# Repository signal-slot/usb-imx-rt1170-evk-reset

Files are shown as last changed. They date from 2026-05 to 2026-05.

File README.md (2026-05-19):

# USB JTAG Reset Dongle for MIMXRT1170-EVKB

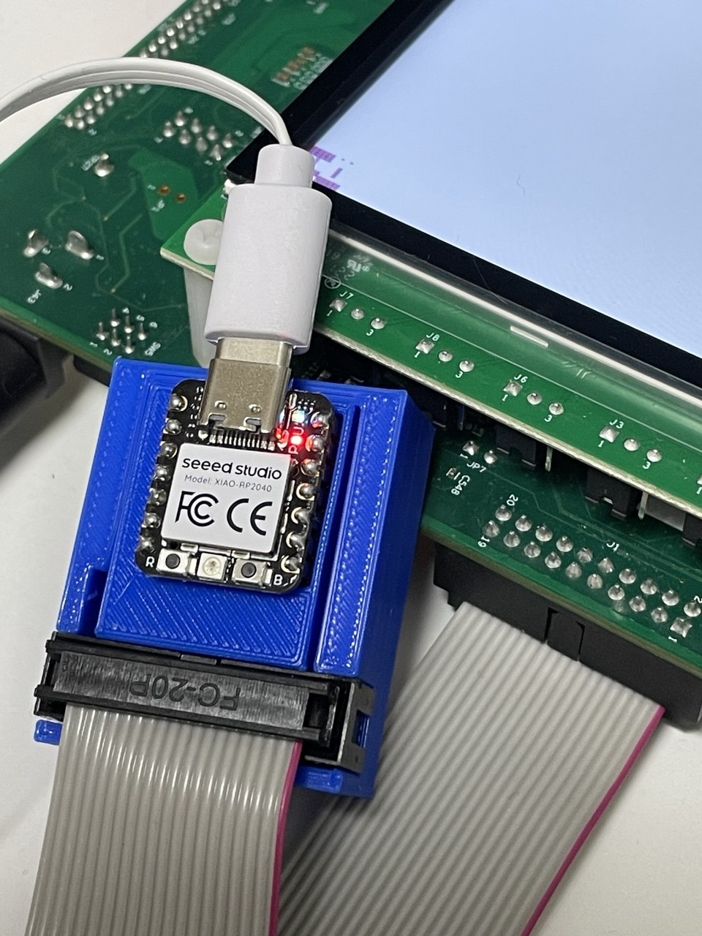
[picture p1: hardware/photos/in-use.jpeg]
MIMXRT1170-EVKB の J1 に接続して USB 経由でリセット


## 目次

1. [目的](#1-目的)
2. [採用した方式](#2-採用した方式)
3. [ハードウェア構成](#3-ハードウェア構成)(うち [フォトリレーとは](#フォトリレーとは))
4. [回路図](#4-回路図)
5. [抵抗の意味](#5-抵抗の意味)
6. [ユニバーサル基板レイアウト](#6-ユニバーサル基板レイアウト)(実機写真は [§6 実機写真](#実機写真) 参照)
7. [Rust ファームウェア方針](#7-rust-ファームウェア方針)
8. [動作確認項目](#8-動作確認項目)

ソースとアセット:

- ファームウェア: [`software/firmware/`](software/firmware/) (RP2040 Rust)
- ホスト CLI: [`software/cli/`](software/cli/) (`rt1170-cli`)
- 3D プリントケース: [`hardware/case/`](hardware/case/)
- 写真: [`hardware/photos/`](hardware/photos/)
- 仕様書(USDM): [`spec/usdm/`](spec/usdm/)

---

## 1. 目的

**最終目標**: AI コーディングエージェント([Claude Code](https://www.anthropic.com/claude-code) 等)が [MIMXRT1170-EVKB](https://www.nxp.com/design/design-center/development-boards-and-designs/i-mx-evaluation-and-development-boards/i-mx-rt1170-evaluation-kit:MIMXRT1170-EVKB) を使った組み込み開発を行う際、デバッガや SDK が **「SW4 を押してください」「ボードをリセットしてください」**と要求する場面を、AI 自身が `rt1170-cli reset` を呼ぶだけで自動化すること。人間がリセットボタンを押すまでループが止まる、という制約から AI を解放する。

そのために、MIMXRT1170-EVKB を Linux PC から USB 経由でリセットできる小型治具を作る。

当初は [SwitchBot](https://www.switch-bot.com/) のように物理的にタクトスイッチを押す案も検討したが、対象が基板上の SMD タクトスイッチであり、グラバーや物理押下機構が現実的でないため、最終的には **JTAG/SWD 20pin コネクタ上の reset 信号を電気的に短絡する方式**を採用する。

MIMXRT1170-EVKB の Hardware User Guide([NXP MIMXRT1170-EVKB ドキュメントページ](https://www.nxp.com/design/design-center/development-boards-and-designs/i-mx-evaluation-and-development-boards/i-mx-rt1170-evaluation-kit:MIMXRT1170-EVKB))では、J1 の JTAG/SWD コネクタに `POR_PIN_RST_B` が `JTAG_nSRST` として出ている。したがって、JTAG 20pin の `nSRST` と `GND` を一瞬短絡すれば、リセットボタン (**SW4**) を押したのと同等の操作ができる。

基本動作:

```text
Linux PC
  |
  | USB
  v
XIAO RP2040
  |
  | GPIO
  v
TLP241A PhotoMOS
  |
  | output contact
  v
JTAG nSRST / POR_PIN_RST_B  ── GND
```

Linux 側からは、例えば以下のように操作する。

```bash
echo "RESET 100" > /dev/ttyACM0
```

これにより、XIAO RP2040 が TLP241A を 100 ms だけ ON し、JTAG `nSRST` を GND に短絡する。

---

## 2. 採用した方式

### 最終方式

**USB CDC + XIAO RP2040 + TLP241A + 20pin JTAG IDC ケーブル**

### 採用理由

- MIMXRT1170-EVKB 側の SMD タクトスイッチを直接触らずに済む
- EVKB 側を改造しなくてよい
- JTAG/SWD 20pin コネクタから `nSRST` と `GND` を取り出せる
- TLP241A により XIAO 側と EVKB 側を絶縁できる
- Linux から `/dev/ttyACM0` 経由で簡単に制御できる
- XIAO RP2040 が手元にあり、Rust ファームウェアを書きやすい
- 13×8 の小型ユニバーサル基板に実装可能

---

## 3. ハードウェア構成

### フォトリレーとは

**フォトリレー**(PhotoMOS, [ソリッドステートリレー (SSR)](https://en.wikipedia.org/wiki/Solid-state_relay) の一種)は、光結合で入力と出力を電気的に絶縁したスイッチ。内部構造はおおよそ次のとおり:

- **入力側**: LED(発光ダイオード)
- **出力側**: MOSFET(機種により SCR や Triac のものもある)
- **絶縁**: LED と MOSFET の間は **光のみ**で結合。電気的には完全に分離されている

LED に電流を流して点灯させると、その光を受けた MOSFET がオンになり、出力側の接点が導通する。LED を消せばオフ。機械式リレーと違ってバウンスがなく、寿命が長く、スイッチング速度も速い。

このプロジェクトで採用している [**TLP241A**](https://akizukidenshi.com/goodsaffix/TLP241A_datasheet_ja_20230524.pdf)(東芝)は、出力 MOSFET が **双方向**(AC/DC どちらも切れる)、耐圧 60 V、`I_FT(max) = 5 mA` でトリガする 1 回路品。DIP-4 パッケージ。

### 主要部品

| 部品 | 用途 |
|---|---|
| [XIAO RP2040](https://wiki.seeedstudio.com/XIAO-RP2040/) | USB CDC デバイス兼 GPIO 制御 |
| [TLP241A](https://akizukidenshi.com/goodsaffix/TLP241A_datasheet_ja_20230524.pdf) | JTAG `nSRST` と `GND` を短絡する PhotoMOS / [フォトリレー](#フォトリレーとは) |
| 20pin IDC フラットケーブル | MIMXRT1170-EVKB の J1 JTAG/SWD コネクタへ接続 |
| 20pin 2×10 ヘッダ / IDC 受け | ユニバーサル基板側で IDC ケーブルを受ける |
| 13×8 ユニバーサル基板 | 実装基板 |
| 1kΩ 抵抗 | TLP241A 入力 LED の電流制限 (詳細は [§5](#5-抵抗の意味)) |
| 100kΩ 抵抗 | XIAO GPIO のプルダウン (詳細は [§5](#5-抵抗の意味)) |
| ピンソケット | XIAO RP2040 を着脱可能にする |

### 使用する信号

#### JTAG 20pin 側

一般的な ARM 20pin JTAG/SWD 配置では以下を使う。

```text
pin15 = nSRST / JTAG_nSRST / POR_PIN_RST_B
pin16 = GND
```

したがって TLP241A の出力側で以下を短絡する。

```text
JTAG pin15  <->  JTAG pin16
```

#### XIAO RP2040 側

XIAO は USB-C が下向きになるように配置する。  
制御ピンは、配置しやすい **D7 / GPIO1** を採用する。

```text
XIAO D7 / GPIO1 -> TLP241A input LED+
XIAO GND        -> TLP241A input LED-
```

---

## 4. 回路図

### 全体回路

TLP241A を中央に置き、**左半分が XIAO 側(LED 入力, 3.3V GND 系)**、**右半分が EVKB 側(MOSFET 出力, EVKB GND 系)**。チップ内部で光結合だけが両者をまたぎ、電気的には絶縁されている。

```text
   XIAO RP2040 側                  TLP241A                    EVKB J1 (JTAG 20pin)
   ─────────────                  ─────────                   ─────────────────────

                                ┌──────────┐
   D7/GPIO1 ●─┬─[ R1  1kΩ ]─────┤ 1      4 ├────────── ● pin 16 (GND, EVKB 側)
              │                 │  │     ║ │
              │                 │  ▼ LED ║ MOSFET   ← LED 点灯時に MOSFET 閉
              │                 │  │     ║ │
              └─[ R2 100kΩ ]──┐ │  │     ║ │
                              │ │  │     ║ │
   XIAO GND ●─────────────────●─┤ 2      3 ├────────── ● pin 15 (nSRST)
                                └──────────┘
                                  ◀────│────▶
                                  入力  │  出力
                                  (LED) │  (MOSFET)
                                        │
                                   絶縁境界(光結合のみ)
```

- pin 1, 2(チップ左) は XIAO 側 GND を基準とした 3.3V 系
- pin 3, 4(チップ右) は EVKB 側 GND を基準とした JTAG 信号
- 両 GND は同電位ではなく、TLP241A 内部で**完全に絶縁**されている

### JTAG 側

```text
MIMXRT1170-EVKB J1 / JTAG 20pin

pin15  nSRST / POR_PIN_RST_B  ---- TLP241A pin3
pin16  GND                    ---- TLP241A pin4
```

### XIAO 側

```text
XIAO D7 / GPIO1  ---- R1 1kΩ ----- TLP241A pin1
XIAO GND         ----------------- TLP241A pin2

XIAO D7 / GPIO1  ---- R2 100kΩ ---- XIAO GND
```

---

## 5. 抵抗の意味

### R1

TLP241A の入力 LED に流れる電流を制限するための抵抗。

- 推奨: **470Ω**
- 採用: **1kΩ**

### R2: 100kΩ

XIAO の GPIO が起動直後やリセット中に浮いて、TLP241A が誤 ON するのを防ぐためのプルダウン抵抗。

```text
XIAO D7/GPIO1 ---- 100kΩ ---- XIAO GND
```

---

## 6. ユニバーサル基板レイアウト

### 前提

- 基板: 13×8 ユニバーサル基板
- ポートレート配置
- 幅 8 穴 × 高さ 13 穴
- 20pin IDC は上側
- XIAO RP2040 は行7〜13
- XIAO は USB-C が下向き
- 20pin IDC は 8穴幅に対して左右 1 ピンずつはみ出す
- 抵抗は TLP241A の左側に置く

### 配置図

13×8 ユニバーサル基板 / 部品面・上から見る(USB-C を下、IDC を上にして縦置き):

部品面(XIAO 未装着、配線とパーツが全部見える):

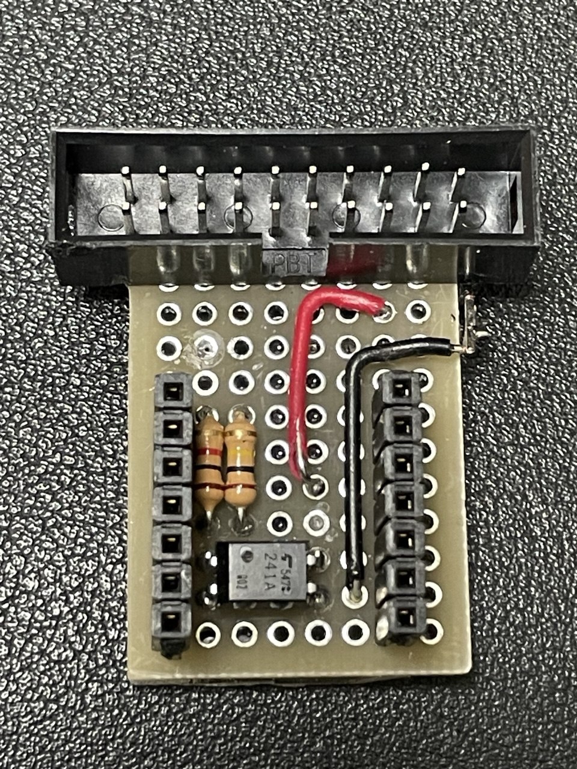
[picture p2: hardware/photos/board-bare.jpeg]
部品面・XIAO 未装着


| | | 1 | 2 | 3 | 4 | 5 | 6 | 7 | 8 | |  |
|:-:|:-:|:-:|:-:|:-:|:-:|:-:|:-:|:-:|:-:|:-:|:-:|
| | | | | | | | | ┌ | ─ | ─ | ┐ |
| r1 | ① | ③ | ⑤ | ⑦ | ⑨ | ⑪ | ⑬ | **⑮** | ⑰ | ⑲ | │ |
| r2 | ② | ④ | ⑥ | ⑧ | ⑩ | ⑫ | ⑭ | **⑯** | ⑱ | ⑳ | │ |
| r3 | | ・ | ・ | ・ | ・ | ・ | ・ | │ | ・ | | │ |
| r4 | | ・ | ・ | ・ | ・ | ┌ | ─ | ┘ | ・ | | │ |
| r5 | | ・ | ・ | ・ | ・ | │ | ┌ | ─ | ─ | ─ | ┘ |
| r6 | | ・ | ・ | ・ | ・ | │ | │ | ・ | ・ | | |
| r7 | | 7️⃣ | ┬ | ┐ | ・ | │ | │ | 6️⃣ | ・ | | |
| r8 | | 8️⃣ | Ｒ | Ｒ | ・ | │ | │ | 5️⃣ | ・ | | |
| r9 | | 9️⃣ | １ | ２ | ・ | │ | │ | 4️⃣ | ・ | | |
| 10 | | 🔟 | │ | │ | ・ | │ | │ | 3️⃣ | ・ | | |
| 11 | | 🔌 | P1 | │ | □ | P3 | │ | 2️⃣ | ・ | | |
| 12 | | ➖ | -2 | ┘ | □ | P4 | ┘ | 1️⃣ | ・ | | |
| 13 | | ➕ | ・ | ・ | ・ | ・ | ・ | 0️⃣ | ・ | | |
| | | | | Ｕ | Ｓ | Ｂ | | | | | |

凡例:

- `①`〜`⑳` … IDC ピン番号(囲み数字)。`⑮` (pin 15 = nSRST) と `⑯` (pin 16 = GND) のみ太字
- `・` … 空のホール
- `0️⃣`〜`9️⃣` `🔟` … XIAO の D0〜D10 ピン穴(囲み数字キーキャップ絵文字)
- `🔌` … 3V3、 `➖` … GND、 `➕` … 5V
- `Ｒ` `Ｒ` … R1 (1kΩ) / R2 (100kΩ) 本体、 `１` `２` … 抵抗ラベル
- `□` … TLP241A のチップ本体、 `P1`〜`P4` … 各ピン
- `┌` `┐` `┘` `─` `│` `┬` … 配線(IDC 渡り線、D7 分岐、R 末端ジャンパ)

XIAO ピン配置(USB-C を下向きにした縦置き、部品面・上から見る):

- **左ソケット**(行6→12): **D7/GPIO1**, D8, D9, D10, 3V3, **GND**, 5V
- **右ソケット**(行6→12): D6, D5, D4, D3, D2, D1, D0

レイアウト要点:

- R1 / R2 は左ソケット直右に縦置き 2 本、どちらも D7/GPIO1 から分岐
- TLP241A は基板中央、**左半分が LED 入力**(XIAO 側 GND を基準)、**右半分が MOSFET 出力**(EVKB 側 GND を基準)
- IDC の渡り線 2 本は中央 trench を縦に走り、TLP241A 右側の P3, P4 へ降下
- XIAO 側 GND と JTAG GND(EVKB 側)は TLP241A 内部で絶縁(直結なし)

### 穴位置(主要ホール)

```text
IDC pin15 (nSRST)       = 行1, 列7        ※ IDC は左右各 1 ピンずつ overhang
IDC pin16 (GND, EVKB側) = 行2, 列7

XIAO D7/GPIO1           = 行6, 列2  (左ソケット最上段)
XIAO GND                = 行11, 列2 (左ソケット下から 2 行目)

TLP241A pin1 (LED+)     = 行10, 列3
TLP241A pin2 (LED−)     = 行11, 列3
TLP241A pin3 (MOSFET)   = 行10, 列6
TLP241A pin4 (MOSFET)   = 行11, 列6
```

配線:

```text
行1列7  IDC pin15 / nSRST   ─── (中央 trench を縦走) ─── 行10列6  TLP241A pin3
行2列7  IDC pin16 / GND     ─── (中央 trench を縦走) ─── 行11列6  TLP241A pin4

行6列2   XIAO D7/GPIO1 ─┬── R1 1kΩ ───────────────────  行10列3  TLP241A pin1
                       └── R2 100kΩ ──┐
                                       │
行11列2 XIAO GND ─────────────────────●─────────────────  行11列3  TLP241A pin2
```

### 実機写真

部品面(XIAO 装着済):

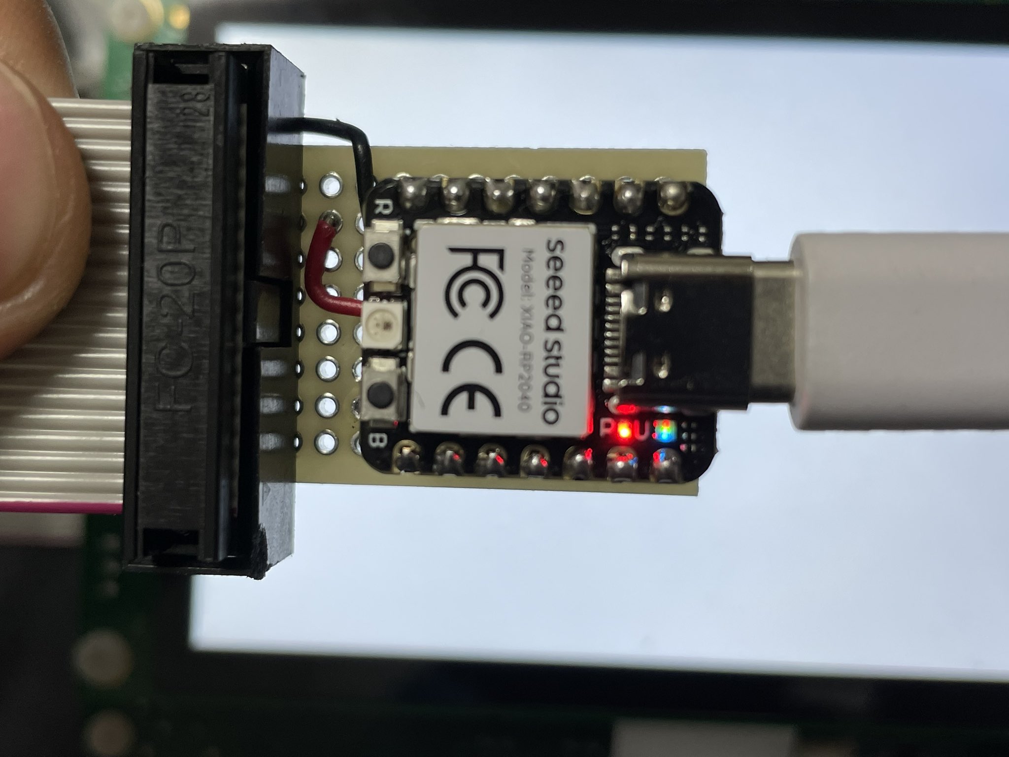
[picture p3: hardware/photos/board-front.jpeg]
部品面・XIAO 装着


はんだ面(基板裏のジャンパ配線):

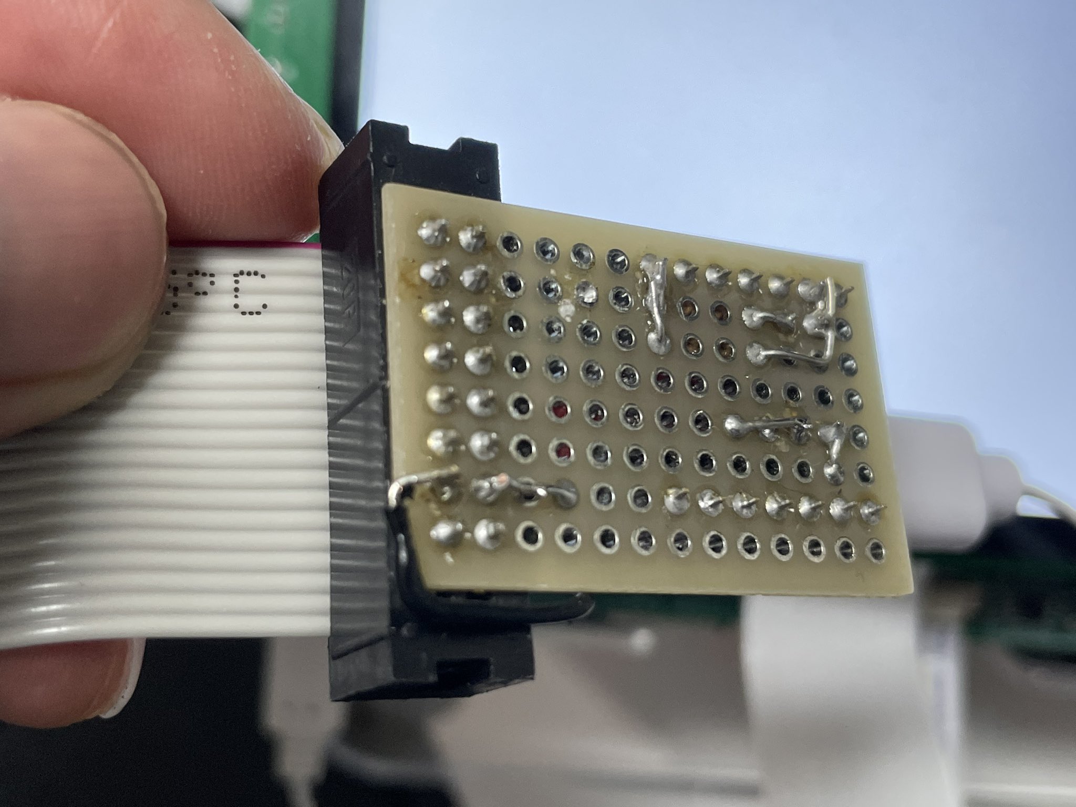
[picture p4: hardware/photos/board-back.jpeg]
はんだ面


側面(TLP241A・IDC・XIAO の位置関係):

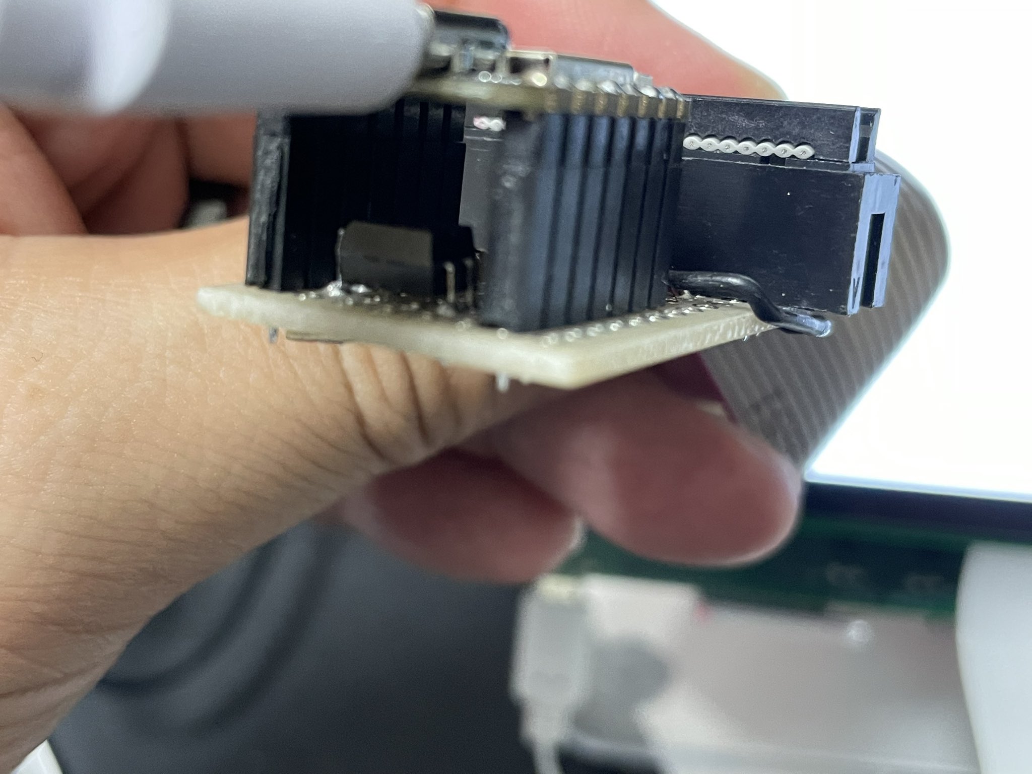
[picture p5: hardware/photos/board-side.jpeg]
側面


3D プリントケース組み込み済:

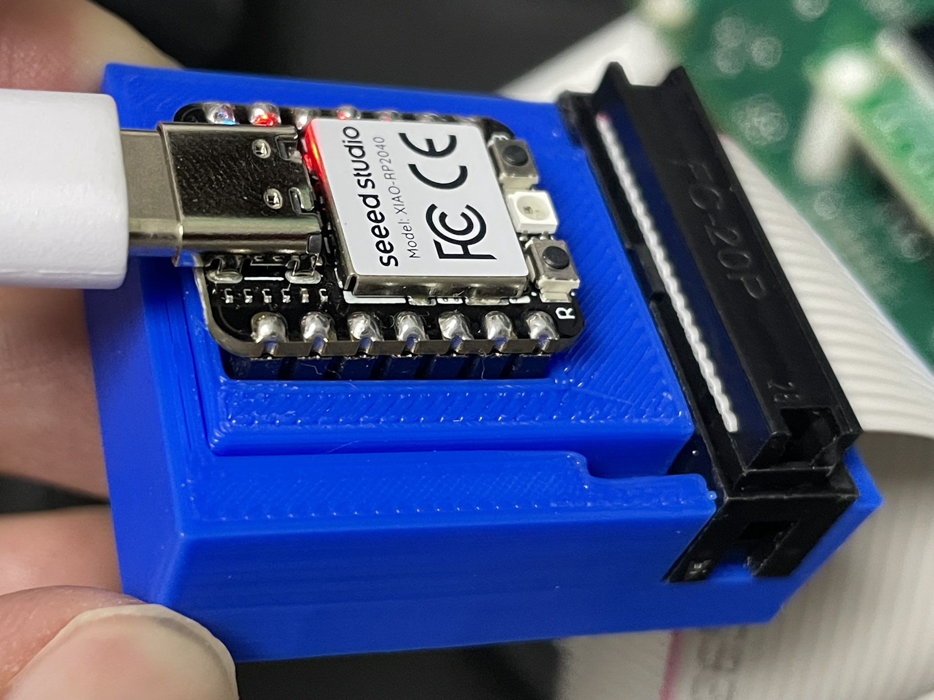
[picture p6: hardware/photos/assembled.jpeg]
ケース組み込み


---

## 7. Rust ファームウェア方針

XIAO RP2040 は USB CDC デバイスとして動作させる。  
Linux からは `/dev/ttyACM0` として見える。

### コマンド仕様

```text
PING
RESET
RESET 100
OFF
```

### 動作

```text
PING       -> PONG
RESET      -> D7/GPIO1 を 100 ms High
RESET 100  -> D7/GPIO1 を 100 ms High
OFF        -> D7/GPIO1 を Low
```

RESET 時:

```text
XIAO D7 High
  -> TLP241A input LED ON
  -> TLP241A output ON
  -> JTAG pin15-pin16 short
  -> MIMXRT1170-EVKB reset
```

安全策:

```text
起動時は必ず D7 Low
RESET時間に上限を設ける
不正コマンドでは何もしない
OFFコマンドを用意する
```

---

## 8. 動作確認項目

EVKB に接続する前に必ず確認する。

### 通常時

```text
JTAG pin15 - pin16 = 非導通
```

### RESET 実行時

```text
JTAG pin15 - pin16 = 一瞬だけ導通
```

### 絶縁確認

```text
XIAO 5V  - JTAG側 = 非導通
XIAO 3V3 - JTAG側 = 非導通
XIAO GND - JTAG GND = 非導通
```

TLP241A を使うため、XIAO 側 GND と EVKB/JTAG 側 GND は直結しない。

---

動作デモ

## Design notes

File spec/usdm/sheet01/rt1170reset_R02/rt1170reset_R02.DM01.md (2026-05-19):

↑ [【rt1170reset_R02】GPIOパルス制御](./rt1170reset_R02.md "【rt1170reset_R02】")

# 【rt1170reset_R02.DM01】GPIO1によるフォトリレー駆動

## 要求

XIAO RP2040 の PIN7 から TLP241A の入力 LED を駆動し、PIN3 と PIN4 の導通で RT1170-EVK の J1 15 番と 16 番を短絡する

### 理由

マイコン側と EVK 側を絶縁したままリセット操作を実現するため

### 説明

PIN7 のシルク名は D7 であり、`seeeduino-xiao-rp2040` BSP 上では `pins.rx` が GPIO1 出力に対応する

## 仕様

| 種別 | 内容 | 仕様番号 |
| --- | --- | --- |
| 仕様 | XIAO RP2040 の PIN7 を `pins.rx` 経由で GPIO1 のデジタル出力として構成する | 【rt1170reset_R02.DM01-01】 |
| 仕様 | PIN7 が High の間だけ TLP241A の PIN1-PIN2 間 LED を点灯させる | 【rt1170reset_R02.DM01-02】 |
| 仕様 | TLP241A の PIN3 と PIN4 の導通により RT1170-EVK の J1 15 番と 16 番を短絡する | 【rt1170reset_R02.DM01-03】 |
| 仕様 | PIN7 が Low のときは TLP241A の出力を非導通とし、J1 15 番と 16 番を開放する | 【rt1170reset_R02.DM01-04】 |

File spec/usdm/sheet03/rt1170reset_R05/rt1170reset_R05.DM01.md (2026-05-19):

↑ [【rt1170reset_R05】ハードウェア接続条件](./rt1170reset_R05.md "【rt1170reset_R05】")

# 【rt1170reset_R05.DM01】配線構成

## 要求

USB ホスト、XIAO RP2040、TLP241A、RT1170-EVK J1 の接続を仕様として固定する

### 理由

実装者が別配線を前提にコードを書いてしまうことを防ぐため

### 説明

XIAO RP2040 の PIN7 は TLP241A の入力 LED を 470Ω 経由で駆動する

## 仕様

| 種別 | 内容 | 仕様番号 |
| --- | --- | --- |
| 仕様 | USB ホストは XIAO RP2040 と USB 接続され、CDC シリアル経由でコマンドを送る | 【rt1170reset_R05.DM01-01】 |
| 仕様 | XIAO RP2040 の PIN7 は 470Ω を介して TLP241A の PIN1 に接続される | 【rt1170reset_R05.DM01-02】 |
| 仕様 | XIAO RP2040 の GND は TLP241A の PIN2 に接続される | 【rt1170reset_R05.DM01-03】 |
| 仕様 | TLP241A の PIN3 と PIN4 は RT1170-EVK の J1 20 ピンの 15 番と 16 番に接続される | 【rt1170reset_R05.DM01-04】 |

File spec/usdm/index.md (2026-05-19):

# rt1170reset

## ヘッダー

| 行 | A | **B** | ~~C~~ | D | E |
|---|---|---|---|---|---|
| 列 | 11.0 | 5.25 | 10.375 | 20.625 | 70.625 |
| 1 | カテゴリ名 | 要求 | 要求ID | 要求仕様 | ← |

## シート一覧

- [1.USBリセットファームウェア](./sheet01/index.md)
- [2.ホスト側将来要求](./sheet02/index.md)
- [3.安全性と運用](./sheet03/index.md)

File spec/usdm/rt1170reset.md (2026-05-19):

# 【rt1170reset】RT1170-EVK USBリセットツール

## 要求

Seeeduino XIAO RP2040 を USB 接続し、PIN7 で TLP241A を駆動して RT1170-EVK の J1 20 ピンの 15 番と 16 番を短時間導通させることでボードをリセットするファームウェアを提供する

### 理由

RT1170-EVK のリセット操作を手元のシェルやコーディングエージェントから安全かつ再現可能に自動実行できるようにするため

### 説明

現行実装は USB CDC シリアル経由の ASCII コマンドで PIN7 のオンオフとパルス幅を制御するファームウェアであり、専用ホスト CLI は未実装である

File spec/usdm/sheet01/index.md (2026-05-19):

↑ [rt1170reset](../index.md)

# 【rt1170reset】1.USBリセットファームウェア

## 要求

[rt1170reset: コンポーネント](../rt1170reset.md "【rt1170reset】")

## 下位要求

- [R01 USB CDCリセットインタフェース](./rt1170reset_R01/rt1170reset_R01.md "【rt1170reset_R01】")
- [R02 GPIOパルス制御](./rt1170reset_R02/rt1170reset_R02.md "【rt1170reset_R02】")

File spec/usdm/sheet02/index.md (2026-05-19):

↑ [rt1170reset](../index.md)

# 【rt1170reset】2.ホスト側将来要求

## 要求

[rt1170reset: コンポーネント](../rt1170reset.md "【rt1170reset】")

## 下位要求

- [R03 非対話CLIリセット実行要求](./rt1170reset_R03/rt1170reset_R03.md "【rt1170reset_R03】")
- [R04 対象デバイス選択要求](./rt1170reset_R04/rt1170reset_R04.md "【rt1170reset_R04】")

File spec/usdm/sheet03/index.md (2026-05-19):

↑ [rt1170reset](../index.md)

# 【rt1170reset】3.安全性と運用

## 要求

[rt1170reset: コンポーネント](../rt1170reset.md "【rt1170reset】")

## 下位要求

- [R05 ハードウェア接続条件](./rt1170reset_R05/rt1170reset_R05.md "【rt1170reset_R05】")
- [R06 エージェント運用性](./rt1170reset_R06/rt1170reset_R06.md "【rt1170reset_R06】")

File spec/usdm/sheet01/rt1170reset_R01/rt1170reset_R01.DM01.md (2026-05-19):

↑ [【rt1170reset_R01】USB CDCリセットインタフェース](./rt1170reset_R01.md "【rt1170reset_R01】")

# 【rt1170reset_R01.DM01】コマンド受付と応答

## 要求

ホストから受信した 1 行単位の ASCII コマンドを解釈し、成功時と失敗時の応答を一意に返す

### 理由

CLI から安定してリセット操作と状態確認を行えるようにするため

### 説明

コマンド名は大文字小文字を区別せず、前後の空白は無視する。成功応答は CRLF 区切り ASCII で返す

## 仕様

| 種別 | 内容 | 仕様番号 |
| --- | --- | --- |
| 仕様 | `PING` を受信したときは `PONG` を返し、リセット出力は変化させない | 【rt1170reset_R01.DM01-01】 |
| 仕様 | `OFF` を受信したときはリセット出力を Low にして `OK OFF` を返す | 【rt1170reset_R01.DM01-02】 |
| 仕様 | `RESET` または `RESET <ms>` を受信したときはパルス実行後に `OK RESET <実際に適用したms>` を返す | 【rt1170reset_R01.DM01-03】 |
| 仕様 | `BOOTSEL` を受信したときは `OK BOOTSEL` を返した後に RP2040 ROM の USB ブートモードへ遷移する | 【rt1170reset_R01.DM01-04】 |
| 仕様 | 未知のコマンドは `ERR` を返す | 【rt1170reset_R01.DM01-05】 |
| 仕様 | コマンド終端は `CR` または `LF` とし、空行は無視する | 【rt1170reset_R01.DM01-06】 |

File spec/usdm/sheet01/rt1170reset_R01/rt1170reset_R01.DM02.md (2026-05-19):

↑ [【rt1170reset_R01】USB CDCリセットインタフェース](./rt1170reset_R01.md "【rt1170reset_R01】")

# 【rt1170reset_R01.DM02】USB CDCデバイス識別

## 要求

ホストが対象デバイスを自動検出できるように USB CDC デバイスとして一意な識別情報を公開する

### 理由

複数のシリアルデバイスが接続された環境でも CLI が誤った機器に接続しないようにするため

### 説明

USB シリアルの通信内容は ASCII コマンドだが、デバイス選択は USB の識別子で行う

## 仕様

| 種別 | 内容 | 仕様番号 |
| --- | --- | --- |
| 仕様 | USB クラスは CDC ACM 相当のシリアルデバイスとして列挙される | 【rt1170reset_R01.DM02-01】 |
| 仕様 | USB VID/PID は `0x1209:0x0001` を使用する | 【rt1170reset_R01.DM02-02】 |
| 仕様 | Product 文字列は `EVKB USB Reset` を公開する | 【rt1170reset_R01.DM02-03】 |
| 仕様 | Serial Number 文字列はホストが選択キーとして利用できる形式で公開する | 【rt1170reset_R01.DM02-04】 |

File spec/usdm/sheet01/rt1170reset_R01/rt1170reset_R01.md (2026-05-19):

↑ [1.USBリセットファームウェア](../index.md)

# 【rt1170reset_R01】USB CDCリセットインタフェース

## 要求

USB CDC シリアル経由でホストからのリセット要求を受け付け、単純で機械処理しやすいテキストプロトコルで応答する

### 理由

ホスト CLI やコーディングエージェントが余計な対話なしで RT1170-EVK を制御できるようにするため

### 説明

コマンドは行区切り ASCII とし、ファームウェアはホストからのコマンド単位で結果を返す

## 下位要求

- [01 コマンド受付と応答](./rt1170reset_R01.DM01.md "【rt1170reset_R01.DM01】")
- [02 USB CDCデバイス識別](./rt1170reset_R01.DM02.md "【rt1170reset_R01.DM02】")

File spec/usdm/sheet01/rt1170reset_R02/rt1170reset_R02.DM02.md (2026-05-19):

↑ [【rt1170reset_R02】GPIOパルス制御](./rt1170reset_R02.md "【rt1170reset_R02】")

# 【rt1170reset_R02.DM02】パルス幅と安全復帰

## 要求

リセット出力のパルス幅を制御し、起動時・異常時を含めて必ず非アサート状態へ戻す

### 理由

EVK のリセット信号を保持し続ける故障モードを避けるため

### 説明

コマンド処理中はブロッキングでもよいが、パルス中も USB の列挙と I/O が破綻しないこと、およびパルス完了後の Low 復帰は必須とする

## 仕様

| 種別 | 内容 | 仕様番号 |
| --- | --- | --- |
| 仕様 | `RESET` のパルス幅未指定時は 100ms を使用する | 【rt1170reset_R02.DM02-01】 |
| 仕様 | 指定可能なパルス幅は 10ms 以上 1000ms 以下とし、範囲外はその範囲に丸める | 【rt1170reset_R02.DM02-02】 |
| 仕様 | 電源投入後は USB 列挙前にリセット出力を Low に設定する | 【rt1170reset_R02.DM02-03】 |
| 仕様 | パルス中は USB デバイスを poll し続け、受信した CDC データは処理せず破棄する | 【rt1170reset_R02.DM02-04】 |
| 仕様 | パルス終了後は必ずリセット出力を Low に戻し、入力行バッファを空に戻す | 【rt1170reset_R02.DM02-05】 |
| 仕様 | 長すぎる入力行や不正入力ではリセット出力をアサートしない | 【rt1170reset_R02.DM02-06】 |

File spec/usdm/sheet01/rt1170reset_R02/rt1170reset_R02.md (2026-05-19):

↑ [1.USBリセットファームウェア](../index.md)

# 【rt1170reset_R02】GPIOパルス制御

## 要求

XIAO RP2040 の PIN7 を用いて TLP241A をオンオフし、RT1170-EVK のリセット信号に対して安全なワンショットパルスを印加する

### 理由

ホストが `RESET` コマンドを送るだけで EVK のリセット動作を再現できるようにするため

### 説明

XIAO の PIN7 は BSP 上では `GPIO1` を出力として扱い、High でフォトリレーを導通させる

## 下位要求

- [01 GPIO1によるフォトリレー駆動](./rt1170reset_R02.DM01.md "【rt1170reset_R02.DM01】")
- [02 パルス幅と安全復帰](./rt1170reset_R02.DM02.md "【rt1170reset_R02.DM02】")

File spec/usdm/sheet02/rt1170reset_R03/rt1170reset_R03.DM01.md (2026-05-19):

↑ [【rt1170reset_R03】非対話CLIリセット実行要求](./rt1170reset_R03.md "【rt1170reset_R03】")

# 【rt1170reset_R03.DM01】サブコマンド提供

## 要求

CLI からファームウェアの主要機能を直接呼び出せるようにサブコマンドを提供する

### 理由

利用者が USB CDC の生プロトコルを覚えなくても必要な操作を実行できるようにするため

### 説明

ここでの CLI は将来実装対象であり、最終的に USB CDC へ ASCII コマンドを送るフロントエンドとして振る舞う

## 仕様

| 種別 | 内容 | 仕様番号 |
| --- | --- | --- |
| 仕様 | `ping` サブコマンドはデバイスへ `PING` を送り、`PONG` を確認する | 【rt1170reset_R03.DM01-01】 |
| 仕様 | `off` サブコマンドはデバイスへ `OFF` を送り、リセット出力解除を要求する | 【rt1170reset_R03.DM01-02】 |
| 仕様 | `reset` サブコマンドはデバイスへ `RESET` または `RESET <ms>` を送り、パルス実行を要求する | 【rt1170reset_R03.DM01-03】 |
| 仕様 | `reset` サブコマンドはパルス幅オプション未指定時に 100ms を既定値として扱う | 【rt1170reset_R03.DM01-04】 |
| 仕様 | `bootsel` サブコマンドはデバイスへ `BOOTSEL` を送り、ファームウェア更新用の USB ブートモード遷移を要求する | 【rt1170reset_R03.DM01-05】 |

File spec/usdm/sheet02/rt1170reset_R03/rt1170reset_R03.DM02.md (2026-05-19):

↑ [【rt1170reset_R03】非対話CLIリセット実行要求](./rt1170reset_R03.md "【rt1170reset_R03】")

# 【rt1170reset_R03.DM02】安定した入出力と終了コード

## 要求

将来実装する CLI の標準入出力と終了コードを安定化し、スクリプトやエージェントから判定可能にする

### 理由

人手と自動化の両方で同じコマンドを安全に利用するため

### 説明

成功判定はデバイス応答と接続状態に基づいて行う

## 仕様

| 種別 | 内容 | 仕様番号 |
| --- | --- | --- |
| 仕様 | CLI は対話プロンプトを表示しない | 【rt1170reset_R03.DM02-01】 |
| 仕様 | 成功時は終了コード 0 を返す | 【rt1170reset_R03.DM02-02】 |
| 仕様 | タイムアウト、デバイス未検出、複数候補、期待外の応答、通信失敗では 0 以外の終了コードを返す | 【rt1170reset_R03.DM02-03】 |
| 仕様 | 成功時の結果は 1 行で標準出力へ表示し、失敗理由は標準エラー出力へ表示する | 【rt1170reset_R03.DM02-04】 |
| 仕様 | `--help` で使用方法とオプション一覧を表示できる | 【rt1170reset_R03.DM02-05】 |

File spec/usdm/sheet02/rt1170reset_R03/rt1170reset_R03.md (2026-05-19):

↑ [2.ホスト側将来要求](../index.md)

# 【rt1170reset_R03】非対話CLIリセット実行要求

## 要求

将来のホスト側ツールとして、USB 経由でファームウェアに接続し、対話なしで `ping` `off` `reset` `bootsel` を実行できる CLI を提供する

### 理由

開発者やコーディングエージェントがシェルコマンド一発で EVK をリセットできるようにするため

### 説明

これは将来要求であり、現時点のリポジトリには専用 CLI 実装は含まれない

## 下位要求

- [01 サブコマンド提供](./rt1170reset_R03.DM01.md "【rt1170reset_R03.DM01】")
- [02 安定した入出力と終了コード](./rt1170reset_R03.DM02.md "【rt1170reset_R03.DM02】")

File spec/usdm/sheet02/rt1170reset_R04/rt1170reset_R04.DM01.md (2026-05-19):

↑ [【rt1170reset_R04】対象デバイス選択要求](./rt1170reset_R04.md "【rt1170reset_R04】")

# 【rt1170reset_R04.DM01】デバイス発見

## 要求

将来の CLI は既定動作として接続済み USB デバイスから対象ファームウェアを探索する

### 理由

利用者が毎回シリアルポート名を調べなくてもコマンドを実行できるようにするため

### 説明

探索条件はファームウェアが公開する USB 識別情報を用いる

## 仕様

| 種別 | 内容 | 仕様番号 |
| --- | --- | --- |
| 仕様 | 自動検出時は USB VID/PID `0x1209:0x0001` を優先条件とする | 【rt1170reset_R04.DM01-01】 |
| 仕様 | Product 文字列 `EVKB USB Reset` を照合条件として利用できる | 【rt1170reset_R04.DM01-02】 |
| 仕様 | 候補が 0 台のときは未検出として失敗終了する | 【rt1170reset_R04.DM01-03】 |
| 仕様 | 候補が複数台のときは曖昧として失敗終了し、明示指定方法を案内する | 【rt1170reset_R04.DM01-04】 |

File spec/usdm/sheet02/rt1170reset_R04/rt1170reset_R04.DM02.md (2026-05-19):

↑ [【rt1170reset_R04】対象デバイス選択要求](./rt1170reset_R04.md "【rt1170reset_R04】")

# 【rt1170reset_R04.DM02】明示選択と接続制御

## 要求

将来の CLI は利用者が接続先を明示でき、通信失敗時は有限時間で終了する

### 理由

複数台接続環境や不安定な USB 環境でも運用不能にならないようにするため

### 説明

明示指定のキーは OS 依存のポート名か USB シリアル番号を想定する

## 仕様

| 種別 | 内容 | 仕様番号 |
| --- | --- | --- |
| 仕様 | CLI は `--port` で OS のシリアルポート名を明示指定できる | 【rt1170reset_R04.DM02-01】 |
| 仕様 | CLI は `--serial-number` で USB シリアル番号を明示指定できる | 【rt1170reset_R04.DM02-02】 |
| 仕様 | CLI は応答待ちの上限時間を指定するオプションを持つ | 【rt1170reset_R04.DM02-03】 |
| 仕様 | タイムアウト時は処理を中断し、失敗終了する | 【rt1170reset_R04.DM02-04】 |

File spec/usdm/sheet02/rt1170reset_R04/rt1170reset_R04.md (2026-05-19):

↑ [2.ホスト側将来要求](../index.md)

# 【rt1170reset_R04】対象デバイス選択要求

## 要求

将来のホスト側 CLI は接続先の XIAO RP2040 を識別し、対象デバイスが一意に決まる場合だけコマンドを送信する

### 理由

他の USB シリアル機器へ誤って `RESET` を送る事故を防ぐため

### 説明

これは将来要求であり、現行実装では CDC デバイス選択をホスト利用者側が担う

## 下位要求

- [01 デバイス発見](./rt1170reset_R04.DM01.md "【rt1170reset_R04.DM01】")
- [02 明示選択と接続制御](./rt1170reset_R04.DM02.md "【rt1170reset_R04.DM02】")

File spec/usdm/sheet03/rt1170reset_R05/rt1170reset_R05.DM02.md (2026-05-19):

↑ [【rt1170reset_R05】ハードウェア接続条件](./rt1170reset_R05.md "【rt1170reset_R05】")

# 【rt1170reset_R05.DM02】リセット動作条件

## 要求

RT1170-EVK のリセットは J1 15 番と 16 番の短時間短絡でのみ実行し、通常時は開放状態を保つ

### 理由

余計な給電や固定短絡によるボード異常を防ぐため

### 説明

TLP241A は接点出力として扱い、EVK 側へ電圧を印加する用途には使わない

## 仕様

| 種別 | 内容 | 仕様番号 |
| --- | --- | --- |
| 仕様 | `RESET` 実行中のみ TLP241A の出力接点を閉じる | 【rt1170reset_R05.DM02-01】 |
| 仕様 | `OFF` 実行時および待機時は TLP241A の出力接点を開く | 【rt1170reset_R05.DM02-02】 |
| 仕様 | リセット操作は J1 15 番と 16 番を短絡する接点動作として実現し、EVK 側へ能動的に電圧を印加しない | 【rt1170reset_R05.DM02-03】 |

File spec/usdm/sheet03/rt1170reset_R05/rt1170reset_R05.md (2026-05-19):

↑ [3.安全性と運用](../index.md)

# 【rt1170reset_R05】ハードウェア接続条件

## 要求

XIAO RP2040、TLP241A、RT1170-EVK の接続関係を固定し、リセット経路を明示する

### 理由

ソフトウェア仕様と現物配線の対応を崩さずに保守できるようにするため

### 説明

USB は XIAO RP2040 の電源供給と CDC 通信に使用し、RT1170-EVK 側のリセット線とは TLP241A で絶縁する

## 下位要求

- [01 配線構成](./rt1170reset_R05.DM01.md "【rt1170reset_R05.DM01】")
- [02 リセット動作条件](./rt1170reset_R05.DM02.md "【rt1170reset_R05.DM02】")

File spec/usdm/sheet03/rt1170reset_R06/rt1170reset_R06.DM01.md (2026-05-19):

↑ [【rt1170reset_R06】エージェント運用性](./rt1170reset_R06.md "【rt1170reset_R06】")

# 【rt1170reset_R06.DM01】利用手順と前提の明文化

## 要求

リポジトリ内の文書から、必要な配線、ファームウェア書き込み、ビルド設定、CLI 実行方法を読み取れるようにする

### 理由

エージェントや新規利用者が外部の口頭説明なしにセットアップできるようにするため

### 説明

手順はホスト OS 差異をまたいで読み替え可能な粒度で記述する

## 仕様

| 種別 | 内容 | 仕様番号 |
| --- | --- | --- |
| 仕様 | 文書には XIAO RP2040 へのファームウェア書き込み方法を記載する | 【rt1170reset_R06.DM01-01】 |
| 仕様 | 文書には `.cargo/config.toml` のターゲット `thumbv6m-none-eabi` と runner `elf2uf2-rs -d` を前提として記載する | 【rt1170reset_R06.DM01-02】 |
| 仕様 | 文書には `build.rs` が `memory.x` を `OUT_DIR` へ配置してリンク解決する前提を記載する | 【rt1170reset_R06.DM01-03】 |
| 仕様 | 文書には USB 接続後に利用する CDC コマンド例を記載し、CLI が未実装ならその旨を明記する | 【rt1170reset_R06.DM01-04】 |
| 仕様 | 文書には USB 識別情報と期待応答文字列を記載する | 【rt1170reset_R06.DM01-05】 |

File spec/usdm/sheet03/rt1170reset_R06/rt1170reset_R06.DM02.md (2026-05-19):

↑ [【rt1170reset_R06】エージェント運用性](./rt1170reset_R06.md "【rt1170reset_R06】")

# 【rt1170reset_R06.DM02】検証可能性

## 要求

CLI とファームウェアの主要振る舞いを順を追って確認できるようにする

### 理由

実機接続時に問題が配線、USB、プロトコルのどこにあるかを切り分けるため

### 説明

自動テストが難しいため、実機前提の受け入れ確認手順を重視する

## 仕様

| 種別 | 内容 | 仕様番号 |
| --- | --- | --- |
| 仕様 | `ping` により接続性とプロトコル応答を確認できる | 【rt1170reset_R06.DM02-01】 |
| 仕様 | `off` により出力解除状態を確認できる | 【rt1170reset_R06.DM02-02】 |
| 仕様 | `reset` により RT1170-EVK の再起動を確認できる | 【rt1170reset_R06.DM02-03】 |
| 仕様 | `bootsel` により RP2040 が USB ブートモードへ遷移することを確認できる | 【rt1170reset_R06.DM02-04】 |

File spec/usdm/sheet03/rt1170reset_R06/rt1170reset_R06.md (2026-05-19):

↑ [3.安全性と運用](../index.md)

# 【rt1170reset_R06】エージェント運用性

## 要求

コーディングエージェントがこのリポジトリ内の成果物だけでリセット操作を再利用できるように、利用条件と検証手順を明文化する

### 理由

人手の補足説明なしでも自動化フローに組み込めるようにするため

### 説明

ここでいうエージェントには Codex や Claude Code のような CLI 実行主体を含む

## 下位要求

- [01 利用手順と前提の明文化](./rt1170reset_R06.DM01.md "【rt1170reset_R06.DM01】")
- [02 検証可能性](./rt1170reset_R06.DM02.md "【rt1170reset_R06.DM02】")

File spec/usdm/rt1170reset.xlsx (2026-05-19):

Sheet: 1.USBリセットファームウェア
カテゴリ名 | 要求 | 要求ID | 要求仕様
 | 要求 | R01 | USB CDC シリアル経由でホストからのリセット要求を受け付け、単純で機械処理しやすいテキストプロトコルで応答する
 |  | 理由 | ホスト CLI やコーディングエージェントが余計な対話なしで RT1170-EVK を制御できるようにするため
 |  | 説明 | コマンドは行区切り ASCII とし、ファームウェアはホストからのコマンド単位で結果を返す
 |  | 要求 | 01 | ホストから受信した 1 行単位の ASCII コマンドを解釈し、成功時と失敗時の応答を一意に返す
 |  |  | 理由 | CLI から安定してリセット操作と状態確認を行えるようにするため
 |  |  | 説明 | コマンド名は大文字小文字を区別せず、前後の空白は無視する。成功応答は CRLF 区切り ASCII で返す
 |  | 仕様 | 【rt1170reset_R01.DM01-01】 | `PING` を受信したときは `PONG` を返し、リセット出力は変化させない
 |  | 仕様 | 【rt1170reset_R01.DM01-02】 | `OFF` を受信したときはリセット出力を Low にして `OK OFF` を返す
 |  | 仕様 | 【rt1170reset_R01.DM01-03】 | `RESET` または `RESET <ms>` を受信したときはパルス実行後に `OK RESET <実際に適用したms>` を返す
 |  | 仕様 | 【rt1170reset_R01.DM01-04】 | `BOOTSEL` を受信したときは `OK BOOTSEL` を返した後に RP2040 ROM の USB ブートモードへ遷移する
 |  | 仕様 | 【rt1170reset_R01.DM01-05】 | 未知のコマンドは `ERR` を返す
 |  | 仕様 | 【rt1170reset_R01.DM01-06】 | コマンド終端は `CR` または `LF` とし、空行は無視する
 |  | 要求 | 02 | ホストが対象デバイスを自動検出できるように USB CDC デバイスとして一意な識別情報を公開する
 |  |  | 理由 | 複数のシリアルデバイスが接続された環境でも CLI が誤った機器に接続しないようにするため
 |  |  | 説明 | USB シリアルの通信内容は ASCII コマンドだが、デバイス選択は USB の識別子で行う
 |  | 仕様 | 【rt1170reset_R01.DM02-01】 | USB クラスは CDC ACM 相当のシリアルデバイスとして列挙される
 |  | 仕様 | 【rt1170reset_R01.DM02-02】 | USB VID/PID は `0x1209:0x0001` を使用する
 |  | 仕様 | 【rt1170reset_R01.DM02-03】 | Product 文字列は `EVKB USB Reset` を公開する
 |  | 仕様 | 【rt1170reset_R01.DM02-04】 | Serial Number 文字列はホストが選択キーとして利用できる形式で公開する
 | 要求 | R02 | XIAO RP2040 の PIN7 を用いて TLP241A をオンオフし、RT1170-EVK のリセット信号に対して安全なワンショットパルスを印加する
 |  | 理由 | ホストが `RESET` コマンドを送るだけで EVK のリセット動作を再現できるようにするため
 |  | 説明 | XIAO の PIN7 は BSP 上では `GPIO1` を出力として扱い、High でフォトリレーを導通させる
 |  | 要求 | 01 | XIAO RP2040 の PIN7 から TLP241A の入力 LED を駆動し、PIN3 と PIN4 の導通で RT1170-EVK の J1 15 番と 16 番を短絡する
 |  |  | 理由 | マイコン側と EVK 側を絶縁したままリセット操作を実現するため
 |  |  | 説明 | PIN7 のシルク名は D7 であり、`seeeduino-xiao-rp2040` BSP 上では `pins.rx` が GPIO1 出力に対応する
 |  | 仕様 | 【rt1170reset_R02.DM01-01】 | XIAO RP2040 の PIN7 を `pins.rx` 経由で GPIO1 のデジタル出力として構成する
 |  | 仕様 | 【rt1170reset_R02.DM01-02】 | PIN7 が High の間だけ TLP241A の PIN1-PIN2 間 LED を点灯させる
 |  | 仕様 | 【rt1170reset_R02.DM01-03】 | TLP241A の PIN3 と PIN4 の導通により RT1170-EVK の J1 15 番と 16 番を短絡する
 |  | 仕様 | 【rt1170reset_R02.DM01-04】 | PIN7 が Low のときは TLP241A の出力を非導通とし、J1 15 番と 16 番を開放する
 |  | 要求 | 02 | リセット出力のパルス幅を制御し、起動時・異常時を含めて必ず非アサート状態へ戻す
 |  |  | 理由 | EVK のリセット信号を保持し続ける故障モードを避けるため
 |  |  | 説明 | コマンド処理中はブロッキングでもよいが、パルス中も USB の列挙と I/O が破綻しないこと、およびパルス完了後の Low 復帰は必須とする
 |  | 仕様 | 【rt1170reset_R02.DM02-01】 | `RESET` のパルス幅未指定時は 100ms を使用する
 |  | 仕様 | 【rt1170reset_R02.DM02-02】 | 指定可能なパルス幅は 10ms 以上 1000ms 以下とし、範囲外はその範囲に丸める
 |  | 仕様 | 【rt1170reset_R02.DM02-03】 | 電源投入後は USB 列挙前にリセット出力を Low に設定する
 |  | 仕様 | 【rt1170reset_R02.DM02-04】 | パルス中は USB デバイスを poll し続け、受信した CDC データは処理せず破棄する
 |  | 仕様 | 【rt1170reset_R02.DM02-05】 | パルス終了後は必ずリセット出力を Low に戻し、入力行バッファを空に戻す
 |  | 仕様 | 【rt1170reset_R02.DM02-06】 | 長すぎる入力行や不正入力ではリセット出力をアサートしない

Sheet: 2.ホスト側将来要求
カテゴリ名 | 要求 | 要求ID | 要求仕様
 | 要求 | R03 | 将来のホスト側ツールとして、USB 経由でファームウェアに接続し、対話なしで `ping` `off` `reset` `bootsel` を実行できる CLI を提供する
 |  | 理由 | 開発者やコーディングエージェントがシェルコマンド一発で EVK をリセットできるようにするため
 |  | 説明 | これは将来要求であり、現時点のリポジトリには専用 CLI 実装は含まれない
 |  | 要求 | 01 | CLI からファームウェアの主要機能を直接呼び出せるようにサブコマンドを提供する
 |  |  | 理由 | 利用者が USB CDC の生プロトコルを覚えなくても必要な操作を実行できるようにするため
 |  |  | 説明 | ここでの CLI は将来実装対象であり、最終的に USB CDC へ ASCII コマンドを送るフロントエンドとして振る舞う
 |  | 仕様 | 【rt1170reset_R03.DM01-01】 | `ping` サブコマンドはデバイスへ `PING` を送り、`PONG` を確認する
 |  | 仕様 | 【rt1170reset_R03.DM01-02】 | `off` サブコマンドはデバイスへ `OFF` を送り、リセット出力解除を要求する
 |  | 仕様 | 【rt1170reset_R03.DM01-03】 | `reset` サブコマンドはデバイスへ `RESET` または `RESET <ms>` を送り、パルス実行を要求する
 |  | 仕様 | 【rt1170reset_R03.DM01-04】 | `reset` サブコマンドはパルス幅オプション未指定時に 100ms を既定値として扱う
 |  | 仕様 | 【rt1170reset_R03.DM01-05】 | `bootsel` サブコマンドはデバイスへ `BOOTSEL` を送り、ファームウェア更新用の USB ブートモード遷移を要求する
 |  | 要求 | 02 | 将来実装する CLI の標準入出力と終了コードを安定化し、スクリプトやエージェントから判定可能にする
 |  |  | 理由 | 人手と自動化の両方で同じコマンドを安全に利用するため
 |  |  | 説明 | 成功判定はデバイス応答と接続状態に基づいて行う
 |  | 仕様 | 【rt1170reset_R03.DM02-01】 | CLI は対話プロンプトを表示しない
 |  | 仕様 | 【rt1170reset_R03.DM02-02】 | 成功時は終了コード 0 を返す
 |  | 仕様 | 【rt1170reset_R03.DM02-03】 | タイムアウト、デバイス未検出、複数候補、期待外の応答、通信失敗では 0 以外の終了コードを返す
 |  | 仕様 | 【rt1170reset_R03.DM02-04】 | 成功時の結果は 1 行で標準出力へ表示し、失敗理由は標準エラー出力へ表示する
 |  | 仕様 | 【rt1170reset_R03.DM02-05】 | `--help` で使用方法とオプション一覧を表示できる
 | 要求 | R04 | 将来のホスト側 CLI は接続先の XIAO RP2040 を識別し、対象デバイスが一意に決まる場合だけコマンドを送信する
 |  | 理由 | 他の USB シリアル機器へ誤って `RESET` を送る事故を防ぐため
 |  | 説明 | これは将来要求であり、現行実装では CDC デバイス選択をホスト利用者側が担う
 |  | 要求 | 01 | 将来の CLI は既定動作として接続済み USB デバイスから対象ファームウェアを探索する
 |  |  | 理由 | 利用者が毎回シリアルポート名を調べなくてもコマンドを実行できるようにするため
 |  |  | 説明 | 探索条件はファームウェアが公開する USB 識別情報を用いる
 |  | 仕様 | 【rt1170reset_R04.DM01-01】 | 自動検出時は USB VID/PID `0x1209:0x0001` を優先条件とする
 |  | 仕様 | 【rt1170reset_R04.DM01-02】 | Product 文字列 `EVKB USB Reset` を照合条件として利用できる
 |  | 仕様 | 【rt1170reset_R04.DM01-03】 | 候補が 0 台のときは未検出として失敗終了する
 |  | 仕様 | 【rt1170reset_R04.DM01-04】 | 候補が複数台のときは曖昧として失敗終了し、明示指定方法を案内する
 |  | 要求 | 02 | 将来の CLI は利用者が接続先を明示でき、通信失敗時は有限時間で終了する
 |  |  | 理由 | 複数台接続環境や不安定な USB 環境でも運用不能にならないようにするため
 |  |  | 説明 | 明示指定のキーは OS 依存のポート名か USB シリアル番号を想定する
 |  | 仕様 | 【rt1170reset_R04.DM02-01】 | CLI は `--port` で OS のシリアルポート名を明示指定できる
 |  | 仕様 | 【rt1170reset_R04.DM02-02】 | CLI は `--serial-number` で USB シリアル番号を明示指定できる
 |  | 仕様 | 【rt1170reset_R04.DM02-03】 | CLI は応答待ちの上限時間を指定するオプションを持つ
 |  | 仕様 | 【rt1170reset_R04.DM02-04】 | タイムアウト時は処理を中断し、失敗終了する

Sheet: 3.安全性と運用
カテゴリ名 | 要求 | 要求ID | 要求仕様
 | 要求 | R05 | XIAO RP2040、TLP241A、RT1170-EVK の接続関係を固定し、リセット経路を明示する
 |  | 理由 | ソフトウェア仕様と現物配線の対応を崩さずに保守できるようにするため
 |  | 説明 | USB は XIAO RP2040 の電源供給と CDC 通信に使用し、RT1170-EVK 側のリセット線とは TLP241A で絶縁する
 |  | 要求 | 01 | USB ホスト、XIAO RP2040、TLP241A、RT1170-EVK J1 の接続を仕様として固定する
 |  |  | 理由 | 実装者が別配線を前提にコードを書いてしまうことを防ぐため
 |  |  | 説明 | XIAO RP2040 の PIN7 は TLP241A の入力 LED を 470Ω 経由で駆動する
 |  | 仕様 | 【rt1170reset_R05.DM01-01】 | USB ホストは XIAO RP2040 と USB 接続され、CDC シリアル経由でコマンドを送る
 |  | 仕様 | 【rt1170reset_R05.DM01-02】 | XIAO RP2040 の PIN7 は 470Ω を介して TLP241A の PIN1 に接続される
 |  | 仕様 | 【rt1170reset_R05.DM01-03】 | XIAO RP2040 の GND は TLP241A の PIN2 に接続される
 |  | 仕様 | 【rt1170reset_R05.DM01-04】 | TLP241A の PIN3 と PIN4 は RT1170-EVK の J1 20 ピンの 15 番と 16 番に接続される
 |  | 要求 | 02 | RT1170-EVK のリセットは J1 15 番と 16 番の短時間短絡でのみ実行し、通常時は開放状態を保つ
 |  |  | 理由 | 余計な給電や固定短絡によるボード異常を防ぐため
 |  |  | 説明 | TLP241A は接点出力として扱い、EVK 側へ電圧を印加する用途には使わない
 |  | 仕様 | 【rt1170reset_R05.DM02-01】 | `RESET` 実行中のみ TLP241A の出力接点を閉じる
 |  | 仕様 | 【rt1170reset_R05.DM02-02】 | `OFF` 実行時および待機時は TLP241A の出力接点を開く
 |  | 仕様 | 【rt1170reset_R05.DM02-03】 | リセット操作は J1 15 番と 16 番を短絡する接点動作として実現し、EVK 側へ能動的に電圧を印加しない
 | 要求 | R06 | コーディングエージェントがこのリポジトリ内の成果物だけでリセット操作を再利用できるように、利用条件と検証手順を明文化する
 |  | 理由 | 人手の補足説明なしでも自動化フローに組み込めるようにするため
 |  | 説明 | ここでいうエージェントには Codex や Claude Code のような CLI 実行主体を含む
 |  | 要求 | 01 | リポジトリ内の文書から、必要な配線、ファームウェア書き込み、ビルド設定、CLI 実行方法を読み取れるようにする
 |  |  | 理由 | エージェントや新規利用者が外部の口頭説明なしにセットアップできるようにするため
 |  |  | 説明 | 手順はホスト OS 差異をまたいで読み替え可能な粒度で記述する
 |  | 仕様 | 【rt1170reset_R06.DM01-01】 | 文書には XIAO RP2040 へのファームウェア書き込み方法を記載する
 |  | 仕様 | 【rt1170reset_R06.DM01-02】 | 文書には `.cargo/config.toml` のターゲット `thumbv6m-none-eabi` と runner `elf2uf2-rs -d` を前提として記載する
 |  | 仕様 | 【rt1170reset_R06.DM01-03】 | 文書には `build.rs` が `memory.x` を `OUT_DIR` へ配置してリンク解決する前提を記載する
 |  | 仕様 | 【rt1170reset_R06.DM01-04】 | 文書には USB 接続後に利用する CDC コマンド例を記載し、CLI が未実装ならその旨を明記する
 |  | 仕様 | 【rt1170reset_R06.DM01-05】 | 文書には USB 識別情報と期待応答文字列を記載する
 |  | 要求 | 02 | CLI とファームウェアの主要振る舞いを順を追って確認できるようにする
 |  |  | 理由 | 実機接続時に問題が配線、USB、プロトコルのどこにあるかを切り分けるため
 |  |  | 説明 | 自動テストが難しいため、実機前提の受け入れ確認手順を重視する
 |  | 仕様 | 【rt1170reset_R06.DM02-01】 | `ping` により接続性とプロトコル応答を確認できる
 |  | 仕様 | 【rt1170reset_R06.DM02-02】 | `off` により出力解除状態を確認できる
 |  | 仕様 | 【rt1170reset_R06.DM02-03】 | `reset` により RT1170-EVK の再起動を確認できる
 |  | 仕様 | 【rt1170reset_R06.DM02-04】 | `bootsel` により RP2040 が USB ブートモードへ遷移することを確認できる

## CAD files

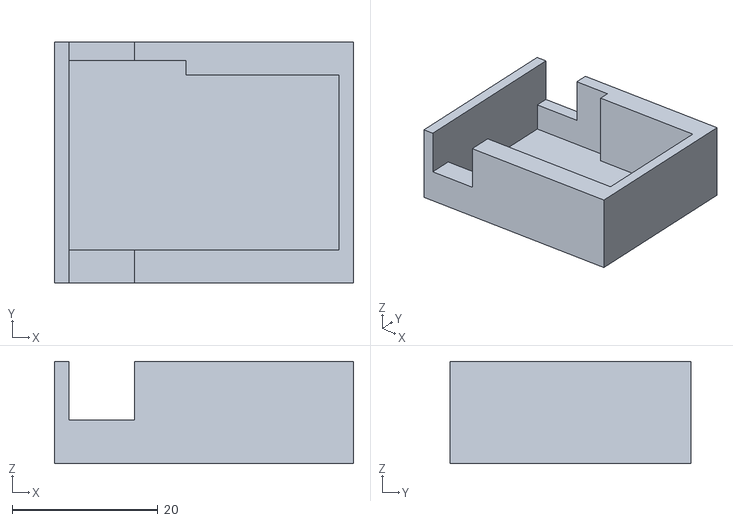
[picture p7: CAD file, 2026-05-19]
hardware/case/usb-reset-dongle-case-lower.stl
41.0 x 33.0 x 14.0

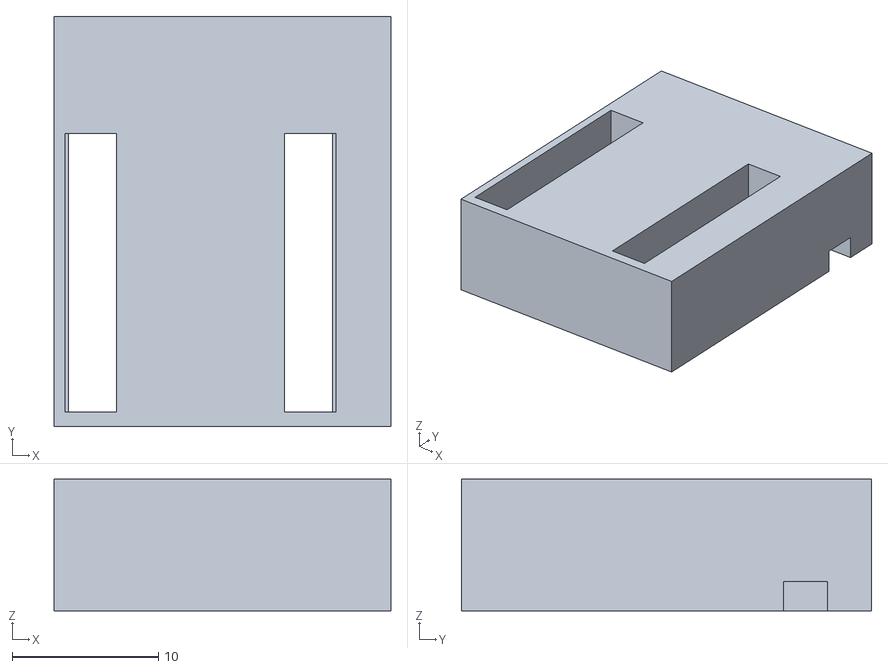
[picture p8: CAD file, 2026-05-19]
hardware/case/usb-reset-dongle-case-upper.stl
23.0 x 28.0 x 9.00

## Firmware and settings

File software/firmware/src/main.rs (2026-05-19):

#![no_std]
#![no_main]

use panic_halt as _;

use seeeduino_xiao_rp2040 as bsp;

use bsp::{
    entry,
    hal::{
        clocks::init_clocks_and_plls,
        gpio::FunctionSioOutput,
        pac,
        sio::Sio,
        timer::Timer,
        usb::UsbBus,
        watchdog::Watchdog,
    },
    Pins, XOSC_CRYSTAL_FREQ,
};

use embedded_hal::digital::OutputPin;

use usb_device::{
    class_prelude::UsbBusAllocator,
    device::{StringDescriptors, UsbDevice, UsbDeviceBuilder, UsbVidPid},
};
use usbd_serial::{SerialPort, USB_CLASS_CDC};

// `seeeduino-xiao-rp2040` の `boot2` feature がデフォルトで
// `BOOT2_FIRMWARE` を `.boot2` セクションに配置してくれるので、
// ここで重ねて宣言する必要はない。

const DEFAULT_RESET_MS: u32 = 100;
const MIN_RESET_MS: u32 = 10;
const MAX_RESET_MS: u32 = 1000;

#[entry]
fn main() -> ! {
    let mut pac = pac::Peripherals::take().unwrap();

    let mut watchdog = Watchdog::new(pac.WATCHDOG);

    let clocks = init_clocks_and_plls(
        XOSC_CRYSTAL_FREQ,
        pac.XOSC,
        pac.CLOCKS,
        pac.PLL_SYS,
        pac.PLL_USB,
        &mut pac.RESETS,
        &mut watchdog,
    )
    .ok()
    .unwrap();

    let sio = Sio::new(pac.SIO);

    let pins = Pins::new(
        pac.IO_BANK0,
        pac.PADS_BANK0,
        sio.gpio_bank0,
        &mut pac.RESETS,
    );

    /*
     * XIAO RP2040:
     *   シルクスクリーン D7 = GPIO1
     *   ※ seeeduino-xiao-rp2040 BSP では D7 のフィールド名は `rx`
     *     (デフォルト機能が UART0 RX のため)
     *
     * 配線:
     *   D7/GPIO1 -> 470Ω -> TLP241A pin1
     *   GND      --------> TLP241A pin2
     *
     * GPIO1 = High → フォトリレー ON  (EVKB RESET 印加)
     * GPIO1 = Low  → フォトリレー OFF (EVKB RESET 解除)
     */
    let mut reset_pin = pins.rx.into_function::<FunctionSioOutput>();

    // 起動直後は必ず OFF。USB ホストの列挙中に EVKB をリセットしないため。
    reset_pin.set_low().ok();

    let timer = Timer::new(pac.TIMER, &mut pac.RESETS, &clocks);

    let usb_bus = UsbBusAllocator::new(UsbBus::new(
        pac.USBCTRL_REGS,
        pac.USBCTRL_DPRAM,
        clocks.usb_clock,
        true,
        &mut pac.RESETS,
    ));

    let mut serial = SerialPort::new(&usb_bus);

    let mut usb_dev = UsbDeviceBuilder::new(&usb_bus, UsbVidPid(0x1209, 0x0001))
        .strings(&[StringDescriptors::default()
            .manufacturer("Signal Slot")
            .product("EVKB USB Reset")
            .serial_number("XIAO-RP2040-RESET-001")])
        .unwrap()
        .device_class(USB_CLASS_CDC)
        .build();

    let mut line_buf = LineBuffer::new();

    loop {
        if usb_dev.poll(&mut [&mut serial]) {
            let mut buf = [0u8; 64];

            if let Ok(n) = serial.read(&mut buf) {
                for &b in &buf[..n] {
                    if let Some(line) = line_buf.push(b) {
                        match handle_line(line, &mut serial) {
                            Action::None => {}
                            Action::SetLow => {
                                reset_pin.set_low().ok();
                                write_all(&mut serial, b"OK OFF\r\n");
                            }
                            Action::SetHigh => {
                                reset_pin.set_high().ok();
                                write_all(&mut serial, b"OK ON\r\n");
                            }
                            Action::Pulse(ms) => {
                                pulse_high(
                                    &mut reset_pin,
                                    &timer,
                                    ms,
                                    &mut usb_dev,
                                    &mut serial,
                                );
                                write_all(&mut serial, b"OK RESET ");
                                write_u32(&mut serial, ms);
                                write_all(&mut serial, b"\r\n");
                                // pulse 中に来た受信ゴミで LineBuffer が
                                // 中途状態のままになっていることがあるので
                                // 念のため空に戻す。
                                line_buf.reset();
                            }
                            Action::Bootsel => {
                                write_all(&mut serial, b"OK BOOTSEL\r\n");
                                // 応答を IN エンドポイントから流し切るまで
                                // 50 ms ほど USB を poll してから ROM に飛ぶ。
                                let start_us = timer.get_counter().ticks();
                                while timer.get_counter().ticks() - start_us
                                    < 50_000
                                {
                                    let _ = usb_dev.poll(&mut [&mut serial]);
                                }
                                bsp::hal::rom_data::reset_to_usb_boot(0, 0);
                                // ROM 呼び出しはチップを reset するので
                                // 戻ってこない。万一戻ってもここで停止。
                                loop {
                                    core::hint::spin_loop();
                                }
                            }
                        }
                    }
                }
            }
        }
    }
}

enum Action {
    None,
    SetLow,
    SetHigh,
    Pulse(u32),
    Bootsel,
}

fn handle_line<B>(line: &str, serial: &mut SerialPort<'_, B>) -> Action
where
    B: usb_device::bus::UsbBus,
{
    let line = line.trim();

    if line.eq_ignore_ascii_case("PING") {
        write_all(serial, b"PONG\r\n");
        return Action::None;
    }

    if line.eq_ignore_ascii_case("OFF") {
        return Action::SetLow;
    }

    if line.eq_ignore_ascii_case("ON") {
        return Action::SetHigh;
    }

    if line.eq_ignore_ascii_case("BOOTSEL") {
        return Action::Bootsel;
    }

    if let Some(ms) = parse_reset_command(line) {
        return Action::Pulse(ms.clamp(MIN_RESET_MS, MAX_RESET_MS));
    }

    write_all(serial, b"ERR\r\n");
    Action::None
}

fn parse_reset_command(line: &str) -> Option<u32> {
    let mut parts = line.split_whitespace();

    let cmd = parts.next()?;

    if !cmd.eq_ignore_ascii_case("RESET") {
        return None;
    }

    match parts.next() {
        Some(ms) => ms.parse::<u32>().ok(),
        None => Some(DEFAULT_RESET_MS),
    }
}

/// HIGH を `ms` ミリ秒だけ駆動して LOW に戻す。
///
/// delay 中も USB を poll し続けるのが要点。さもないと:
///   - ホスト → デバイスへの CDC OUT データがエンドポイント FIFO に滞留し、
///     pulse 完了後にまとめて読み出されて「謎の ERR 連発」になる。
///   - デバイス → ホストへの IN にも応答が遅れて、ホストの再送/再列挙を
///     誘発することがある。
/// pulse 中に受信したバイトは LineBuffer には流さず破棄する。pulse 中に
/// 別コマンドを受け付けてしまうとリセット線の挙動が予測不能になるため。
fn pulse_high<P, B>(
    reset_pin: &mut P,
    timer: &Timer,
    ms: u32,
    usb_dev: &mut UsbDevice<'_, B>,
    serial: &mut SerialPort<'_, B>,
) where
    P: OutputPin,
    B: usb_device::bus::UsbBus,
{
    reset_pin.set_high().ok();

    let start_us = timer.get_counter().ticks();
    let target_us = start_us + ms as u64 * 1000;

    while timer.get_counter().ticks() < target_us {
        if usb_dev.poll(&mut [serial]) {
            let mut sink = [0u8; 64];
            let _ = serial.read(&mut sink);
        }
    }

    reset_pin.set_low().ok();
}

fn write_all<B: usb_device::bus::UsbBus>(serial: &mut SerialPort<'_, B>, mut bytes: &[u8]) {
    while !bytes.is_empty() {
        match serial.write(bytes) {
            Ok(0) | Err(_) => return,
            Ok(n) => bytes = &bytes[n..],
        }
    }
}

fn write_u32<B: usb_device::bus::UsbBus>(serial: &mut SerialPort<'_, B>, mut v: u32) {
    let mut buf = [0u8; 10];
    let mut i = buf.len();

    loop {
        i -= 1;
        buf[i] = b'0' + (v % 10) as u8;
        v /= 10;
        if v == 0 {
            break;
        }
    }

    write_all(serial, &buf[i..]);
}

struct LineBuffer {
    buf: [u8; 64],
    len: usize,
}

impl LineBuffer {
    const fn new() -> Self {
        Self {
            buf: [0; 64],
            len: 0,
        }
    }

    fn reset(&mut self) {
        self.len = 0;
    }

    fn push(&mut self, b: u8) -> Option<&str> {
        match b {
            b'\r' | b'\n' => {
                if self.len == 0 {
                    return None;
                }

                let line = core::str::from_utf8(&self.buf[..self.len]).ok();

                self.len = 0;

                line
            }
            _ => {
                if self.len < self.buf.len() {
                    self.buf[self.len] = b;
                    self.len += 1;
                } else {
                    // 入力が長すぎたら破棄。
                    self.len = 0;
                }

                None
            }
        }
    }
}

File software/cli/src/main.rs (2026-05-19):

//! Host-side CLI for the XIAO RP2040 "USB iMX RT1170 EVK Reset" firmware.
//!
//! Talks to the firmware over its USB CDC ACM port using the same
//! line-delimited ASCII protocol described in the repo-root `README.md` §8
//! (and implemented in `../../firmware/src/main.rs`):
//!
//!   PING            -> PONG
//!   RESET [<ms>]    -> OK RESET <ms>
//!   OFF             -> OK OFF
//!   BOOTSEL         -> OK BOOTSEL  (then chip reboots into RPI-RP2)
//!
//! The serial port is opened in raw 8N1 mode by the `serialport` crate, so
//! the kernel TTY layer's default ECHO / canonical mode does not create
//! the feedback loop that bare `cat > /dev/ttyACM*` style tools suffer from.

use anyhow::{bail, Context, Result};
use clap::{Parser, Subcommand};
use serialport::SerialPort;
use std::time::{Duration, Instant};

const VID: u16 = 0x1209;
const PID: u16 = 0x0001;

/// Control the XIAO RP2040 USB iMX RT1170 EVK reset firmware.
#[derive(Parser)]
#[command(version, about, long_about = None)]
struct Cli {
    /// Serial device path. Default: auto-detect by USB VID:PID = 1209:0001.
    #[arg(short, long, global = true)]
    port: Option<String>,

    #[command(subcommand)]
    cmd: Cmd,
}

#[derive(Subcommand)]
enum Cmd {
    /// Liveness check (expects PONG).
    Ping,
    /// Pulse RESET HIGH for <ms> milliseconds, then return to LOW.
    /// Firmware clamps to 10..=1000.
    Reset {
        #[arg(default_value_t = 100)]
        ms: u32,
    },
    /// Drive RESET LOW (deassert).
    Off,
    /// Drive RESET HIGH (hold the photo-relay asserted indefinitely until `off`).
    On,
    /// Reboot the XIAO into BOOTSEL / RPI-RP2 mode for re-flashing.
    Bootsel,
}

fn find_port() -> Result<String> {
    for p in serialport::available_ports().context("enumerate serial ports")? {
        if let serialport::SerialPortType::UsbPort(info) = &p.port_type {
            if info.vid == VID && info.pid == PID {
                return Ok(p.port_name);
            }
        }
    }
    bail!(
        "no USB CDC device matching VID:PID {:04x}:{:04x} found (pass --port to override)",
        VID,
        PID
    );
}

fn open_port(path: &str) -> Result<Box<dyn SerialPort>> {
    // Baud rate is ignored by USB CDC, but the crate requires one.
    serialport::new(path, 115_200)
        .timeout(Duration::from_millis(200))
        .open()
        .with_context(|| format!("open {}", path))
}

/// Send `command\n`, then read until we see a newline or `total` elapses.
/// Returns the reply with trailing CR/LF stripped.
fn exchange(port: &mut dyn SerialPort, command: &str, total: Duration) -> Result<String> {
    // Drop anything already buffered (stale replies, echo loops, etc).
    let _ = port.clear(serialport::ClearBuffer::Input);

    let mut tx = command.as_bytes().to_vec();
    tx.push(b'\n');
    port.write_all(&tx).context("write")?;
    port.flush().ok();

    let deadline = Instant::now() + total;
    let mut out = Vec::<u8>::new();
    let mut buf = [0u8; 256];

    while Instant::now() < deadline && !out.contains(&b'\n') {
        match port.read(&mut buf) {
            Ok(0) => std::thread::sleep(Duration::from_millis(5)),
            Ok(n) => out.extend_from_slice(&buf[..n]),
            Err(e) if e.kind() == std::io::ErrorKind::TimedOut => continue,
            Err(e) => return Err(e).context("read"),
        }
    }

    Ok(String::from_utf8_lossy(&out)
        .replace("\r\n", "\n")
        .trim_end_matches('\n')
        .to_string())
}

fn main() -> Result<()> {
    let cli = Cli::parse();
    let path = match cli.port.clone() {
        Some(p) => p,
        None => find_port()?,
    };
    let mut port = open_port(&path)?;

    let (request, wait, expected_prefix) = match &cli.cmd {
        Cmd::Ping => ("PING".to_string(), Duration::from_millis(500), "PONG"),
        Cmd::Reset { ms } => (
            format!("RESET {}", ms),
            // Pulse blocks the firmware for up to `ms` ms before replying;
            // give it that plus a fixed slack.
            Duration::from_millis(u64::from((*ms).min(1000)) + 400),
            "OK RESET",
        ),
        Cmd::Off => ("OFF".to_string(), Duration::from_millis(500), "OK OFF"),
        Cmd::On => ("ON".to_string(), Duration::from_millis(500), "OK ON"),
        Cmd::Bootsel => (
            "BOOTSEL".to_string(),
            Duration::from_millis(300),
            "OK BOOTSEL",
        ),
    };

    let reply = exchange(&mut *port, &request, wait).unwrap_or_default();
    println!("{}", reply);

    if !reply.starts_with(expected_prefix) {
        // BOOTSEL is best-effort: the device may unmount before we read.
        if !matches!(cli.cmd, Cmd::Bootsel) {
            std::process::exit(1);
        }
    }
    Ok(())
}
